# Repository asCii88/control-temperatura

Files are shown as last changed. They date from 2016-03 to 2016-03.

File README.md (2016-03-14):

# control-temperatura
Room temperature control through web interface. RF network of sensor/actuators

* Board --> Contine los archivos necesarios para realizar los PCB

* Codigo Fuente Varios --> Contiene el codigo para arduino del Esclavo y el Master y el programa serial

* Proyecto --> Pagina Web

Para Wamp: C:\wamp\www
Para XAMPP: C:\xampp\htdocs

* sistema --> Base de datos

Para Wamp: C:\wamp\bin\mysql\mysql5.6.17\data
Para XAMPP: C:\xampp\mysql\data .

Librerias necesarias:
DHT-sensor-library-master
RF24-master
mysql-connector-net-6.9.8

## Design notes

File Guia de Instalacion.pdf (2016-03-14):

Sistema de control de temperatura

Guía de Instalación

Gesuelli Pinto, Lautaro; Pardo, Rodrigo

Contacto: ingcomp.lau@gmail.com, ascii88@gmail.com

Facultad de Informática, UNLP, 50 y 120, La Plata

1

- Instalar XAMPP en la computadora (explicado en la Entrega final Apéndice A).

Luego ubicar la carpeta Proyecto en el directorio Htdocs de XAMPP. Podría ser:

C:\xampp\htdocs.

En caso de tener instalado Wamp podría ser: C:\wamp\www

- Instalar la base de datos, insertar la carpeta sistema en:

C:\xampp\mysql\data

En caso de tener instalado Wamp podría ser: C:\wamp\bin\mysql\mysql5.6.17\data

- Ejecutar XAMPP.
- Para configurar la base de datos (si fuera necesario) ejecutar WAMP e ir a:

http://localhost/phpmyadmin/index.php

- Ingresar en el navegador a la web: localhost/Proyecto
- Instalar MySqlConnector para que el programa serial se pueda comunicar con la BD

MySql: mysql-connector-net-6.9.8.msi

https://dev.mysql.com/downloads/connector/net/6.9.html

- Encender los esclavos, poniendo el jumper correspondiente
- Conectar un cable Usb entre el módulo master y la PC.
- | Ejecutar | el | programa | serial | interfazMasterBD | (Codigo | Fuente

Varios\interfazMasterBD\interfazMasterBD\bin\Debug\ interfazMasterBD.exe) en

la PC con el parámetro por consola del puerto en que está conectado el modulo

master (Ejemplo: COM1, COM2, COM3, etc).

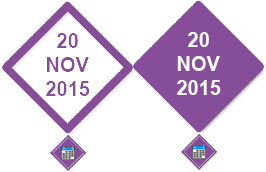
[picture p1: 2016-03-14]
Proyecto/images/calendario.png

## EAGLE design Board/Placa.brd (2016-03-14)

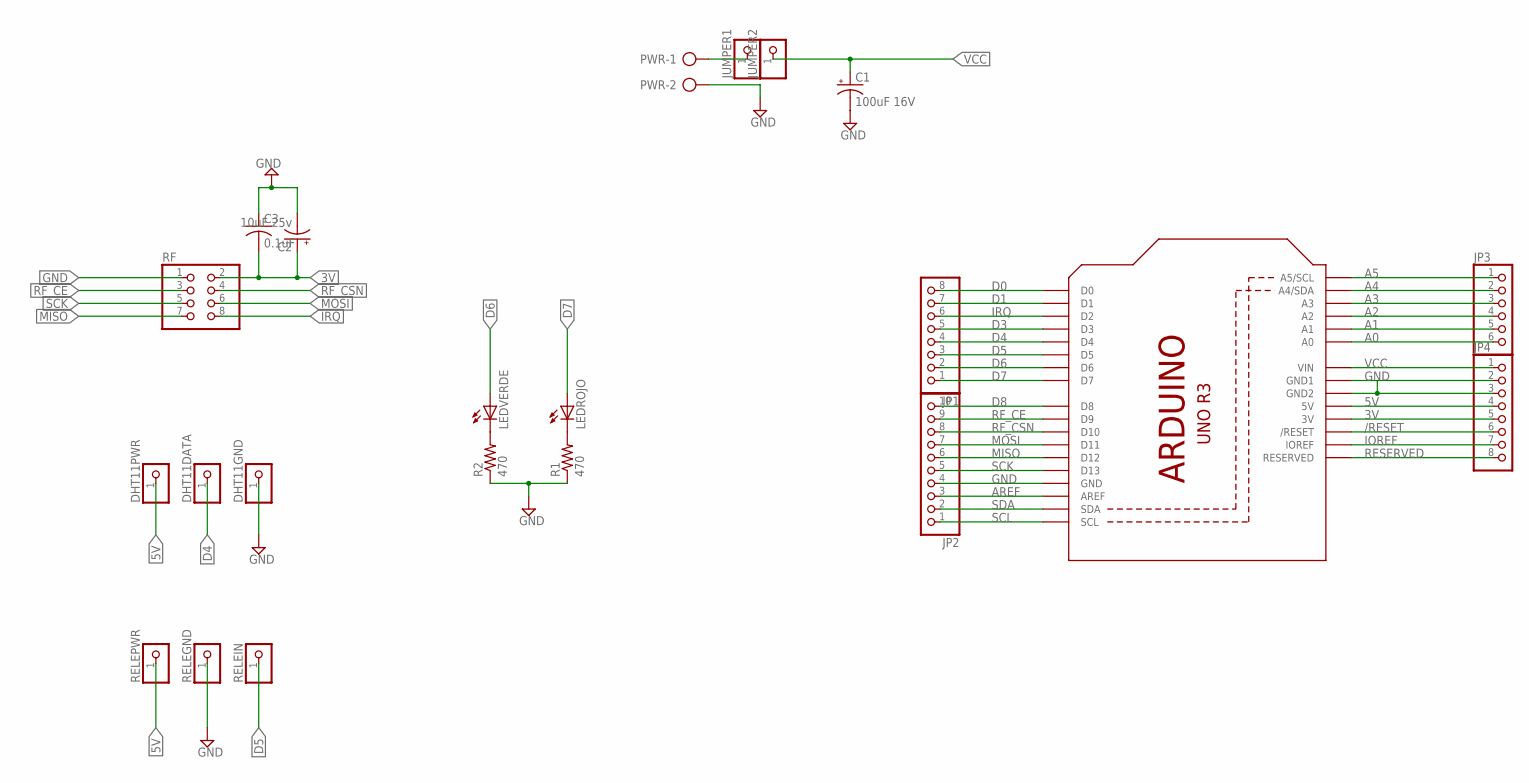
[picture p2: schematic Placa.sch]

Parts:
C1: 100uF 16V; E2,5-7
C2: 10uF 25v; E2,5-7
C3: 0.1uF; C050-024X044
DHT11DATA, DHT11GND, DHT11PWR: PINHD-1X1; 1X01
JP1, JP4: PINHD-1X8; 1X08
JP2: PINHD-1X10; 1X10
JP3: PINHD-1X6; 1X06
JUMPER1, JUMPER2: PINHD-1X1; 1X01
LEDROJO: LED5MM
LEDVERDE: LED5MM
PWR: AK500/2-H
R1, R2: 470; 0204/7
RELEGND: PINHD-1X1; 1X01
RELEIN: PINHD-1X1; 1X01
RELEPWR: PINHD-1X1; 1X01
RF: PINHD-2X4; 2X04
U1: ARDUINOR3-DIMENSION; ARDUINOR3

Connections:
3V: C2.+, C3.2, JP4.5, RF.2, U1.3V
5V: DHT11PWR.1, JP4.4, RELEPWR.1, U1.5V
/RESET: JP4.6, U1.RESET (/RESET)
A0: JP3.6, U1.A0
A1: JP3.5, U1.A1
A2: JP3.4, U1.A2
A3: JP3.3, U1.A3
A4: JP3.2, U1.A4 (A4/SDA)
A5: JP3.1, U1.A5 (A5/SCL)
AREF: JP2.3, U1.AREF
D0: JP1.8, U1.D0
D1: JP1.7, U1.D1
D3: JP1.5, U1.D3
D4: DHT11DATA.1, JP1.4, U1.D4
D5: JP1.3, RELEIN.1, U1.D5
D6: JP1.2, LEDVERDE.A, U1.D6
D7: JP1.1, LEDROJO.A, U1.D7
D8: JP2.10, U1.D8
GND: C1.-, C2.-, C3.1, DHT11GND.1, JP2.4, JP4.2, JP4.3, PWR.2, R1.1, R2.1, RELEGND.1, RF.1, U1.GND, U1.GND1, U1.GND2
IOREF: JP4.7, U1.IOREF
IRQ: JP1.6, RF.8, U1.D2
MISO: JP2.6, RF.7, U1.D12
MOSI: JP2.7, RF.6, U1.D11
unnamed: LEDVERDE.K (C), R2.2
unnamed: LEDROJO.K (C), R1.2
unnamed: JUMPER1.1, PWR.1
RESERVED: JP4.8, U1.RESERVED
RF_CE: JP2.9, RF.3, U1.D9
RF_CSN: JP2.8, RF.4, U1.D10
SCK: JP2.5, RF.5, U1.D13
SCL: JP2.1, U1.SCL
SDA: JP2.2, U1.SDA
VCC: C1.+, JP4.1, JUMPER2.1, U1.VIN

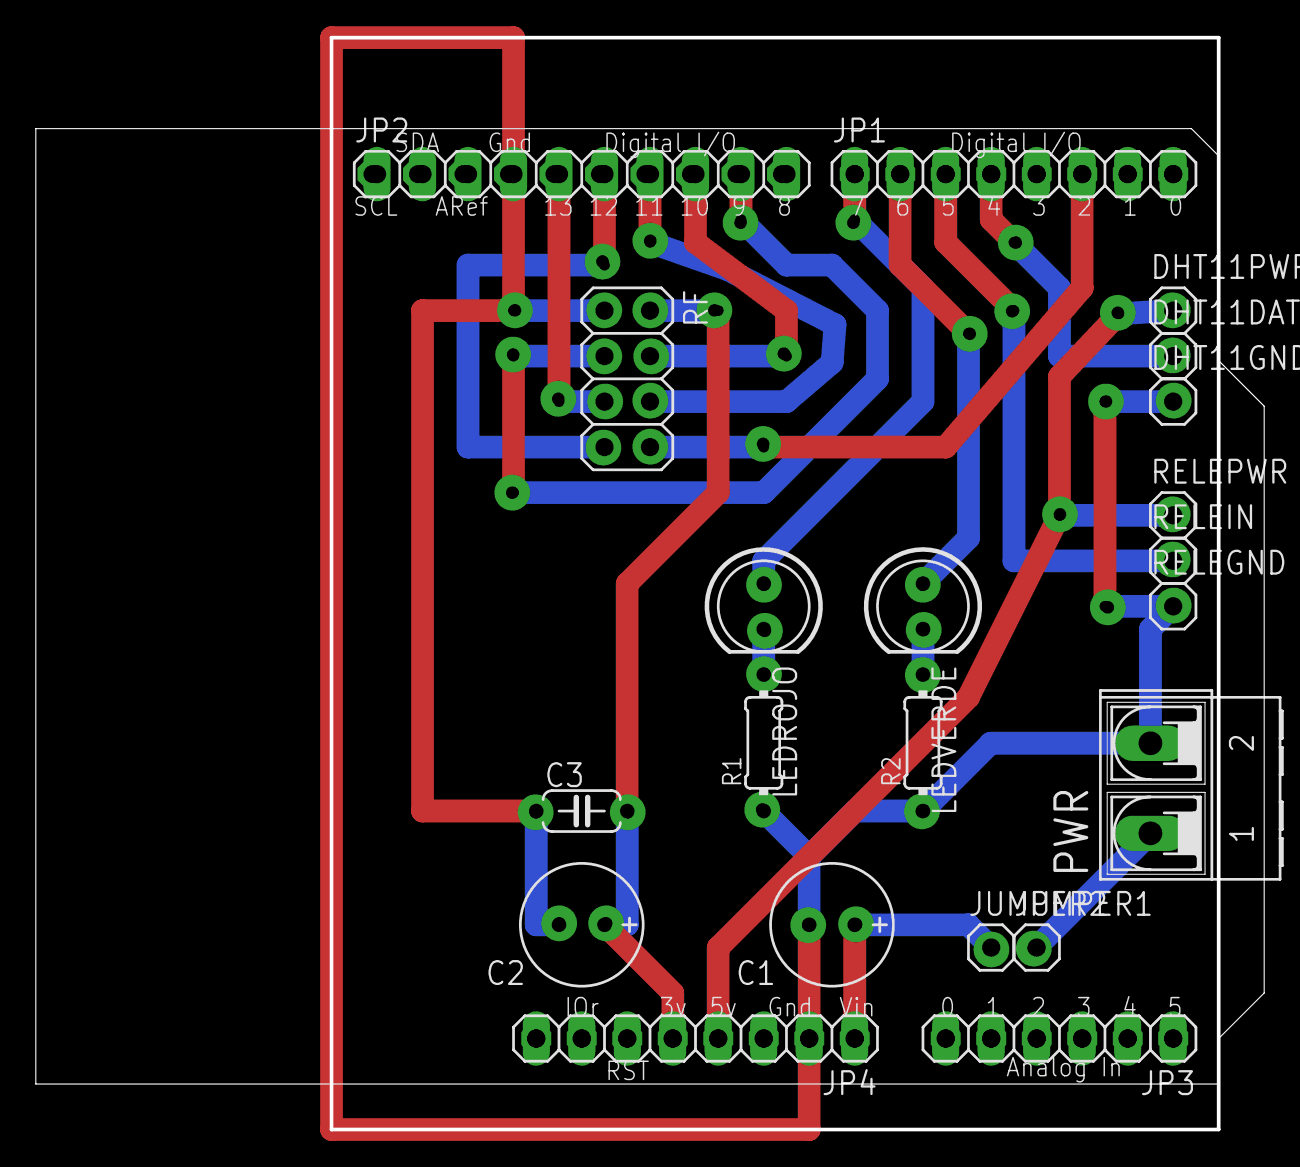
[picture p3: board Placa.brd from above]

Board: 2 copper layers, 68.6 x 61.0 mm, 22 parts (0 on the bottom side), 33 nets.

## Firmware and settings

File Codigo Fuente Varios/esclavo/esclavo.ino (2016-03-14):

int temperaturaDeseada;
int pb;
struct _valores {
  byte temperaturaActual;
  byte potencia;
  bool estado;
};
_valores valores;

#include "mensajeRF.h"
#include "sleep.h"
#include "DHT.h"
#include "rele.h"
#include "printf.h"
#define DHTPIN 4     // El pin digital al que se conecta el sensor DHT
#define DHTTYPE DHT11   // Modelo del DHT

//Inicializar el DHT
DHT dht(DHTPIN, DHTTYPE);

//Pines de leds
#define LED_ROJO 6
#define LED_VERDE 7


void setup() {
  //Valores iniciales
  valores.temperaturaActual = 0;
  valores.estado = true;
  valores.potencia = 0;
  temperaturaDeseada = 0;
  pb = 10;

  //Inicialización de entrada salida digital
  pinMode(2, INPUT_PULLUP);
  pinMode(LED_ROJO, OUTPUT);
  pinMode(LED_VERDE, OUTPUT);

  //Inicialización de puertos de relé
  inicializarRele();

  //Configuración del watchdog
  setup_watchdog(wdt_8s);
  
  //Iniciar módulo RF
  iniciarRF();
}

void loop(void) {
  int banda, salida;
  MensajeRF mensajeEntrante;
  delay(1000);

  //Leer valor de temperatura
  valores.temperaturaActual = (byte)dht.readTemperature();
  
  //Encender el led correspondiente
  if ( valores.estado) {
    digitalWrite(LED_VERDE, HIGH);
    digitalWrite(LED_ROJO, LOW);
  } else {
    digitalWrite(LED_ROJO, HIGH);
    digitalWrite(LED_VERDE, LOW);
  }

  //Encender o apagar relé, calcular potencia
  if (( valores.estado) & ( valores.temperaturaActual < temperaturaDeseada)) {
    //potencia --> CONTROL PROPORCIONAL
    banda = (pb * temperaturaDeseada) / 100; //pb es la constante para definir la banda
    salida = ((temperaturaDeseada - valores.temperaturaActual) * 100) / banda;
    if (salida > 100) {
      encenderRele();
      valores.potencia = 100;
    } else if (salida < 0) {
      apagarRele();
      valores.potencia = 0;
    } else {
      encenderRele();
      valores.potencia = salida;
    }
  } else {
    apagarRele();
    valores.potencia = 0;
  }

  //Entrar en modo de bajo consumo
  do_sleep();

  //Recibir y procesar mensaje de radiofrecuencia
  while (radio.available()) {
    radio.read(&mensajeEntrante, sizeof(MensajeRF));
    switch (mensajeEntrante.byteControl) {
      case CMD_NOP: {
          break;
        }
      case SET_TEMP: {
          temperaturaDeseada = mensajeEntrante.dato;
          break;
        }
      case SET_ESTADO: {
          valores.estado = (bool)mensajeEntrante.dato;
          break;
        }
    }
    //Escribir el payload del ACK
    radio.writeAckPayload(1, &valores, sizeof(_valores));
  }
}

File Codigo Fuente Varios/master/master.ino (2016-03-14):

struct _valores {
  byte temperaturaActual;
  byte potencia;
  bool estado;
};
_valores valores;


unsigned int segundos = 20;

#include "comandos.h"
#include "esclavos.h"
#include "mensajesRF.h"
#include "mensajes.h"


void setup() {

  //Generar la tabla para el cálculo del CRC de los mensajes serie
  generarTablaCRC();

  //Codificación fija de las direcciones de los esclavos
  esclavos[0].direccion = 0xF0F0F0F0D2LL;
  esclavos[1].direccion = 0xF0F0F0F0C3LL;

  //Inicialización del serie
  Serial.begin(57600);
  while (!Serial) {
    ; // esperar al puerto serie a que se conecte. Necesario para puertos USB nativos únicamente
  }
  establishContact();  // Enviar un byte para establecer el contacto hasta que la PC responda
  
  //Iniciar la radio
  iniciarRF();
}

void loop(void) {
  Mensaje mensajeEntrante;

  //Cada 20 segundos
  if (segundos >= 20) {//Solicitar estado de todos los esclavos
    segundos = 0;
    for (int i = 0; i < CANTIDAD_ESCLAVOS; i++) {
      enviarMensajeRF(&(esclavos[i]), CMD_NOP, 0);
    }
  }

  //Recibir y procesar mensajes del puerto serie
  while (recibirMensajeSerie(&mensajeEntrante)) {
    procesarMensajeSerie(&mensajeEntrante);
    delay(50);
  }

  //Esperar 1 segundo
  delay(1000);
  segundos++;
}


void establishContact() {
  while (Serial.available() <= 0) {
    Serial.print('A');   // enviar una A mayúscula
    delay(300);
  }
  Serial.read();
}
